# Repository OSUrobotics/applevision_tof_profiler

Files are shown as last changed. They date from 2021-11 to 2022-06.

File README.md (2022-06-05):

# Applevision ToF Profiler

This repository contains all of the code/models required to create the distance sensor characterization setup used by the Apple Vision capstone project. More information on this setup and it's findings can be found in the handoff document TODO.

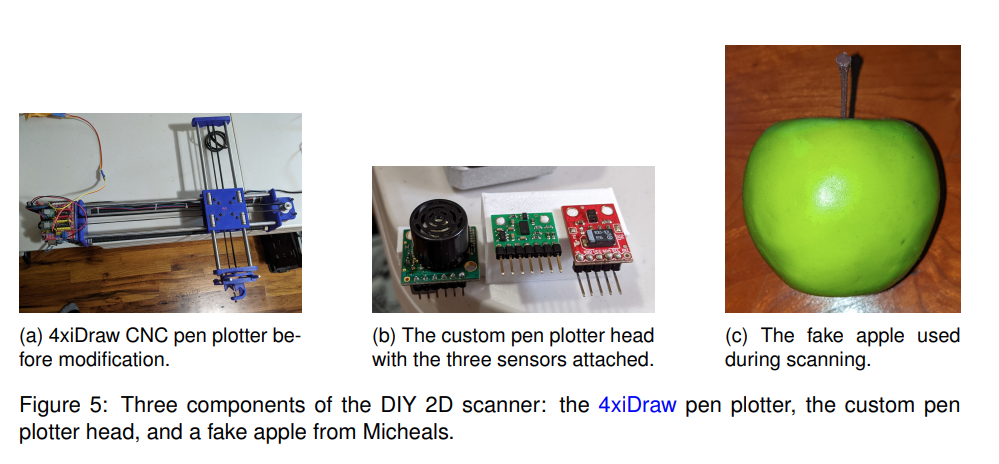
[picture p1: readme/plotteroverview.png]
Diagram from the handoff document showing the pen plotter, sensor testing rig, and fake apple that was scanned


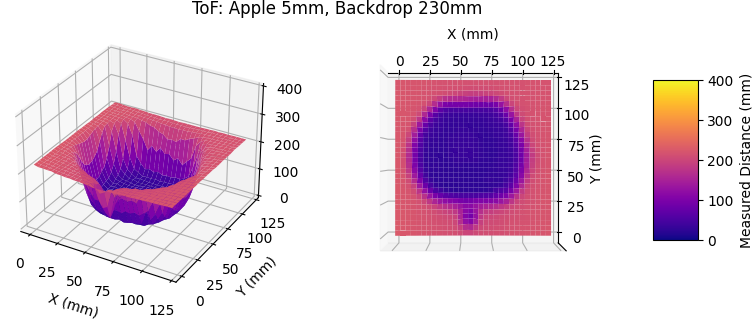
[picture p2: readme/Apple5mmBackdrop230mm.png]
Sample apple scan taken using the VL53L0X ToF sensor


## Repository Structure

```mermaid
flowchart LR
    ultra[MB1232 Ultrasonic Sensor]
    tof[VL53L0X ToF Sensor]
    apd[APDS9960 Proximity Sensor]
    feather[Feather M0]
    plot["4xiDraw Pen Plotter (grbl v1.1h)"]
    comp[Plotter Script]
    data[(CSV Data)]

    ultra --> feather
    tof --> feather
    apd --> feather
    feather <--> comp
    comp <--> plot
    comp --> data
```

This repository splits components of the testing rig into subfolders:
* [`data/`](data/) - Raw CSV data of the apple scans. See the [format document](./data/format.md) for more information.
* [`models/`](models/) - CAD model of the custom pen plotter head in various formats. Originally designed in Autodesk Fusion 360.
* [`plotter_firmware/`](plotter_firmware/) - PlatformIO firmware for a [Feather M0](https://www.adafruit.com/product/2772) to relay sensor readings from the plotter head to the computer.
* [`plotter_script/`](plotter_script/) - Python script which controls the pen plotter and collects data from the sensors.
* [`scripts/`](scripts/) - Scripts to visualize, model, and animate the data collected.

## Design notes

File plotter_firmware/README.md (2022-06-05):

# Plotter Head Firmware

This folder contains a [PlatformIO](https://platformio.org/) project for firmware on a [Feather M0](https://www.adafruit.com/product/2772) which reads three distance sensors and relays the data through a serial port. Sensors are mounted to the custom pen plotter head and wires are connected to the Feather as shown in the wiring diagram below.

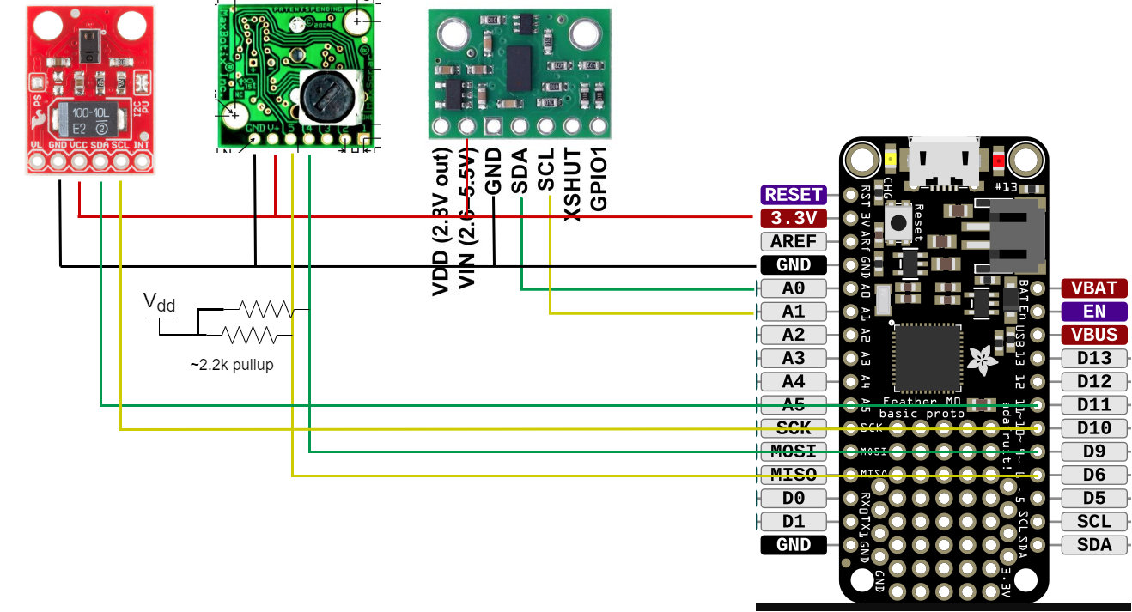
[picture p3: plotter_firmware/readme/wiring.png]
Wiring diagram for the plotter head


Once connected, the Feather M0 will listen on the USB serial port for commands:
* `m`: Take a measurement and print out the result in JSON format.
* `r`: Print `ok` if initialized correctly.

An example of interaction while using this device (input from computer is shown using >):
```console
Init
Ready!
> m
{"lidar": 23, "intensity": 255, "ultra": 20}
> r
ok
```

## I2C

To prevent stupid electrical/driver issues with I2C, each sensor is given it's own I2C bus which it control with impunity. Since the Feather M0 only has one hardware I2C bus, software busses are used on regular GPIO pins. The [`lib`](lib) folder contains sensor drivers that were modified to use a software I2C driver instead of the default `Wire` library (which uses the hardware one).

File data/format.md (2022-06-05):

# Data Format

This folder contains raw readings from the three distance sensors at various XY points. The title of the CSV corresponds to a scanning setup as described in section 2.1.4 of the handoff document TODO. There are four columns present in each CSV:

* `x`, `y` - 2D displacement in millimeters from the top left corner of the scan area.
* `intensity` - Raw value from the APDS9960 proximity sensor ADC. Value is a single byte (0-255). Gain, pulse length, and other sensor settings used during the scan can be found in the [sensor code](../plotter_firmware/src/main.cpp).
* `ultra` - Measured distance in centimeters from the MB1213 ultrasonic sensor.
* `lidar` - Measured distance in millimeters from the VL53L0X ToF sensor. Adafruit's `VL53L0X_SENSE_HIGH_ACCURACY` profile was used for measurement: specific setting values can be found under [`Adafruit_VL53L0X::configSensor`](../plotter_firmware/lib/Adafruit_VL53L0X-master/src/Adafruit_VL53L0X.cpp).

All data files measured a 160mm by 160mm area with a 4mm increment. Five measurements were taken at each grid point to minimize error caused by stopping/starting.

For examples of processing this data, see the scripts in [`visualization_scripts`](../visualization_scripts).

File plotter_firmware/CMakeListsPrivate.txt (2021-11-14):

# !!! WARNING !!! AUTO-GENERATED FILE, PLEASE DO NOT MODIFY IT AND USE
# https://docs.platformio.org/page/projectconf/section_env_build.html#build-flags
#
# If you need to override existing CMake configuration or add extra,
# please create `CMakeListsUser.txt` in the root of project.
# The `CMakeListsUser.txt` will not be overwritten by PlatformIO.

set(CMAKE_CONFIGURATION_TYPES "Debug" CACHE STRING "Build Types reflect PlatformIO Environments" FORCE)

set(CLION_SVD_FILE_PATH "$ENV{HOMEDRIVE}$ENV{HOMEPATH}/.platformio/platforms/atmelsam/misc/svd/ATSAMD21G18A.svd" CACHE FILEPATH "Peripheral Registers Definitions File" FORCE)

SET(CMAKE_C_COMPILER "$ENV{HOMEDRIVE}$ENV{HOMEPATH}/.platformio/packages/toolchain-gccarmnoneeabi/bin/arm-none-eabi-gcc.exe")
SET(CMAKE_CXX_COMPILER "$ENV{HOMEDRIVE}$ENV{HOMEPATH}/.platformio/packages/toolchain-gccarmnoneeabi/bin/arm-none-eabi-g++.exe")
SET(CMAKE_CXX_FLAGS "-fno-rtti -fno-exceptions -std=gnu++11 -fno-threadsafe-statics -Os -ggdb3 -g3 -fasynchronous-unwind-tables -Os -ffunction-sections -fdata-sections -Wall -mcpu=cortex-m0plus -mthumb -nostdlib --param max-inline-insns-single=500 -Wno-expansion-to-defined")
SET(CMAKE_C_FLAGS "-std=gnu11 -Os -ggdb3 -g3 -fasynchronous-unwind-tables -Os -ffunction-sections -fdata-sections -Wall -mcpu=cortex-m0plus -mthumb -nostdlib --param max-inline-insns-single=500 -Wno-expansion-to-defined")

SET(CMAKE_C_STANDARD 11)
set(CMAKE_CXX_STANDARD 11)

if (CMAKE_BUILD_TYPE MATCHES "Debug")
    add_definitions(-DPLATFORMIO=50203)
    add_definitions(-DARDUINO_SAMD_ZERO)
    add_definitions(-DARDUINO_SAMD_FEATHER_M0)
    add_definitions(-DARM_MATH_CM0PLUS)
    add_definitions(-D__SAMD21G18A__)
    add_definitions(-DARDUINO=10805)
    add_definitions(-DF_CPU=48000000L)
    add_definitions(-DUSBCON)
    add_definitions(-DUSB_VID=0x239A)
    add_definitions(-DUSB_PID=0x800B)
    add_definitions(-DUSB_PRODUCT="Adafruit Feather M0")
    add_definitions(-DUSB_MANUFACTURER=\"Adafruit\")
    add_definitions(-DARDUINO_ARCH_SAMD)
    add_definitions(-DUSB_CONFIG_POWER=100)
    add_definitions(-DARDUINO_SAMD_ADAFRUIT)

    include_directories("${CMAKE_CURRENT_LIST_DIR}/include")
    include_directories("${CMAKE_CURRENT_LIST_DIR}/src")
    include_directories("${CMAKE_CURRENT_LIST_DIR}/lib/Adafruit_VL53L0X-master/src")
    include_directories("${CMAKE_CURRENT_LIST_DIR}/.pio/libdeps/Debug/SlowSoftWire")
    include_directories("${CMAKE_CURRENT_LIST_DIR}/.pio/libdeps/Debug/SlowSoftI2CMaster")
    include_directories("${CMAKE_CURRENT_LIST_DIR}/.pio/libdeps/Debug/FeatherTrace/src")
    include_directories("${CMAKE_CURRENT_LIST_DIR}/.pio/libdeps/Debug/Adafruit Arduino Zero ASF Core Library")
    include_directories("$ENV{HOMEDRIVE}$ENV{HOMEPATH}/.platformio/packages/framework-arduino-samd-adafruit/libraries/SPI")
    include_directories("${CMAKE_CURRENT_LIST_DIR}/.pio/libdeps/Debug/Adafruit Zero DMA Library")
    include_directories("${CMAKE_CURRENT_LIST_DIR}/.pio/libdeps/Debug/Adafruit Zero DMA Library/utility")
    include_directories("$ENV{HOMEDRIVE}$ENV{HOMEPATH}/.platformio/packages/framework-arduino-samd-adafruit/libraries/Wire")
    include_directories("$ENV{HOMEDRIVE}$ENV{HOMEPATH}/.platformio/packages/framework-cmsis/CMSIS/Core/Include")
    include_directories("$ENV{HOMEDRIVE}$ENV{HOMEPATH}/.platformio/packages/framework-cmsis-atmel/CMSIS/Device/ATMEL")
    include_directories("$ENV{HOMEDRIVE}$ENV{HOMEPATH}/.platformio/packages/framework-arduino-samd-adafruit/cores/arduino")
    include_directories("$ENV{HOMEDRIVE}$ENV{HOMEPATH}/.platformio/packages/framework-arduino-samd-adafruit/libraries/Adafruit_TinyUSB_Arduino/src/arduino")
    include_directories("$ENV{HOMEDRIVE}$ENV{HOMEPATH}/.platformio/packages/framework-cmsis/CMSIS/DSP/Include")
    include_directories("$ENV{HOMEDRIVE}$ENV{HOMEPATH}/.platformio/packages/framework-arduino-samd-adafruit/variants/feather_m0")
    include_directories("$ENV{HOMEDRIVE}$ENV{HOMEPATH}/.platformio/packages/framework-arduino-samd-adafruit/libraries/Adafruit_TinyUSB_Arduino/src")
    include_directories("${CMAKE_CURRENT_LIST_DIR}/lib/Adafruit_APDS9960-master")
    include_directories("${CMAKE_CURRENT_LIST_DIR}/lib/Adafruit_BusIO-master")
    include_directories("$ENV{HOMEDRIVE}$ENV{HOMEPATH}/.platformio/packages/framework-arduino-samd-adafruit/libraries/Adafruit_ZeroDMA")
    include_directories("$ENV{HOMEDRIVE}$ENV{HOMEPATH}/.platformio/packages/framework-arduino-samd-adafruit/libraries/Adafruit_ZeroDMA/utility")
    include_directories("$ENV{HOMEDRIVE}$ENV{HOMEPATH}/.platformio/packages/framework-arduino-samd-adafruit/libraries/CI_Tests")
    include_directories("$ENV{HOMEDRIVE}$ENV{HOMEPATH}/.platformio/packages/framework-arduino-samd-adafruit/libraries/HID")
    include_directories("$ENV{HOMEDRIVE}$ENV{HOMEPATH}/.platformio/packages/framework-arduino-samd-adafruit/libraries/I2S/src")
    include_directories("$ENV{HOMEDRIVE}$ENV{HOMEPATH}/.platformio/packages/framework-arduino-samd-adafruit/libraries/SAMD_AnalogCorrection/src")
    include_directories("$ENV{HOMEDRIVE}$ENV{HOMEPATH}/.platformio/packages/framework-arduino-samd-adafruit/libraries/SDU/src")
    include_directories("$ENV{HOMEDRIVE}$ENV{HOMEPATH}/.platformio/packages/framework-arduino-samd-adafruit/libraries/Servo/src")
    include_directories("$ENV{HOMEDRIVE}$ENV{HOMEPATH}/.platformio/packages/framework-arduino-samd-adafruit/libraries/USBHost/src")
    include_directories("$ENV{HOMEDRIVE}$ENV{HOMEPATH}/.platformio/packages/toolchain-gccarmnoneeabi/arm-none-eabi/include/c++/9.3.1")
    include_directories("$ENV{HOMEDRIVE}$ENV{HOMEPATH}/.platformio/packages/toolchain-gccarmnoneeabi/arm-none-eabi/include/c++/9.3.1/arm-none-eabi")
    include_directories("$ENV{HOMEDRIVE}$ENV{HOMEPATH}/.platformio/packages/toolchain-gccarmnoneeabi/lib/gcc/arm-none-eabi/9.3.1/include")
    include_directories("$ENV{HOMEDRIVE}$ENV{HOMEPATH}/.platformio/packages/toolchain-gccarmnoneeabi/lib/gcc/arm-none-eabi/9.3.1/include-fixed")
    include_directories("$ENV{HOMEDRIVE}$ENV{HOMEPATH}/.platformio/packages/toolchain-gccarmnoneeabi/arm-none-eabi/include")

    FILE(GLOB_RECURSE EXTRA_LIB_SOURCES
        ${CMAKE_CURRENT_LIST_DIR}/.pio/libdeps/Debug/*.*
    )
endif()

FILE(GLOB_RECURSE SRC_LIST
    ${CMAKE_CURRENT_LIST_DIR}/src/*.*
    ${CMAKE_CURRENT_LIST_DIR}/lib/*.*
    ${CMAKE_CURRENT_LIST_DIR}/test/*.*
)

list(APPEND SRC_LIST ${EXTRA_LIB_SOURCES})

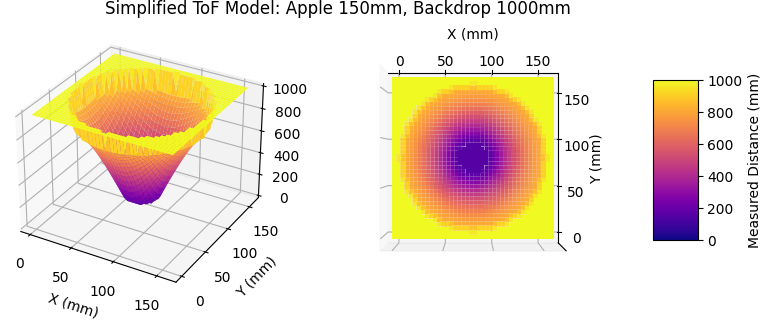
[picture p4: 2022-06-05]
readme/model.png

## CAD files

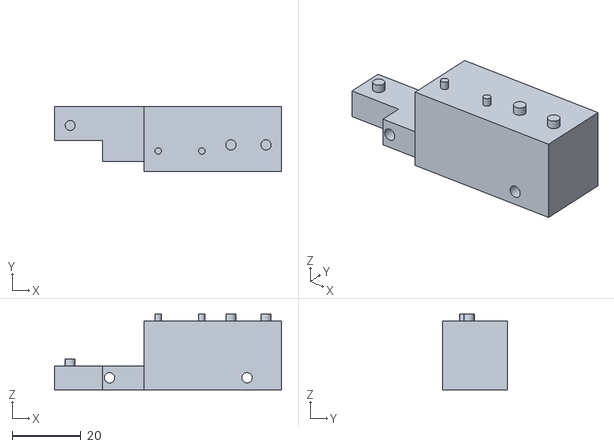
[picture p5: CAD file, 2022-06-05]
models/PenPlotterHead.stl
66.0 x 19.0 x 22.0

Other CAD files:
models/PenPlotterHead.f3z
models/PenPlotterHead.obj

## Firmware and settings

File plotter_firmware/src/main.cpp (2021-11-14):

#include <stdnoreturn.h>
#include <Arduino.h>
#include <Adafruit_APDS9960_SoftWire.h>
#include "wiring_private.h"
#include "FeatherTrace.h"
#include "Adafruit_VL53L0X.h"
#include "SlowSoftI2CMaster.h"
#include "SlowSoftWire.h"

constexpr uint8_t MATBOTIX_WRITE_ADDR = 224;
constexpr uint8_t MATBOTIX_TAKE_READING = 81;
constexpr uint8_t MATBOTIX_READ_ADDR = 225;

FEATHERTRACE_BIND_ALL()

SlowSoftWire lidar_i2c(A0, A1, false);
Adafruit_VL53L0X lidar;
SlowSoftWire apds_i2c(11, 10, false);
Adafruit_APDS9960 intensity;
SlowSoftI2CMaster ultra_i2c(9, 6, true);

void fail(const char* const msg) {
    Serial.println(msg);
    FeatherTrace::Fault(FeatherTrace::FAULT_USER);
}

void setup() {
    // put your setup code here, to run once:
    Serial.begin(115200);
    while(!Serial);
    if (FeatherTrace::DidFault())
      FeatherTrace::PrintFault(Serial);
    Serial.flush();
    // set the watchdog timer to 8 seconds
    FeatherTrace::StartWDT(FeatherTrace::WDTTimeout::WDT_8S);

    Serial.println("Init");
    if (!lidar.begin(VL53L0X_I2C_ADDR, true, &lidar_i2c, Adafruit_VL53L0X::VL53L0X_SENSE_HIGH_ACCURACY))
        fail("Lidar init");

    if (!intensity.begin(200, APDS9960_AGAIN_1X, 0x39, &apds_i2c))
        fail("Intensity init");
    intensity.setProxGain(APDS9960_PGAIN_4X);
    intensity.setLED(APDS9960_LEDDRIVE_100MA, APDS9960_LEDBOOST_100PCNT);
    intensity.setProxPulse(APDS9960_PPULSELEN_16US, 8);
    intensity.enableProximity(true);

    if (!ultra_i2c.i2c_init())
        fail("ultra i2c init");
    if (!ultra_i2c.i2c_start(MATBOTIX_WRITE_ADDR))
        fail("ultra not connected");
    ultra_i2c.i2c_stop();

    MARK;
    Serial.println("Ready!");
    Serial.flush();
}

void take_reading() {
    if (!ultra_i2c.i2c_start(MATBOTIX_WRITE_ADDR))
        fail("ultra not connected");
    ultra_i2c.i2c_write(MATBOTIX_TAKE_READING);
    ultra_i2c.i2c_stop();

    VL53L0X_RangingMeasurementData_t measure;
    lidar.rangingTest(&measure, false);

    bool lidar_valid = false;
    uint16_t lidar_dist = 0;
    if (measure.RangeStatus != 4) {
        lidar_valid = true;
        lidar_dist = measure.RangeMilliMeter;
    }
    else
        lidar_valid = false;

    uint16_t prox_dist = intensity.readProximity();

    if (!ultra_i2c.i2c_start_wait(MATBOTIX_READ_ADDR))
        fail("ultra not connected read");
    uint8_t high = ultra_i2c.i2c_read(false);
    uint8_t low = ultra_i2c.i2c_read(false);
    ultra_i2c.i2c_stop();
    uint16_t ultra_dist = ((uint16_t)high << 8) | (uint16_t)low;

    char buf[1024];
    if (lidar_valid)
        snprintf(buf, sizeof(buf), R"({"lidar": %hu, "intensity": %hu, "ultra": %hu})", lidar_dist, prox_dist, ultra_dist);
    else
        snprintf(buf, sizeof(buf), R"({"intensity": %hu, "ultra": %hu})", prox_dist, ultra_dist);
    Serial.println(buf);
}

void loop() {
    MARK;
    while (!Serial.available())
        MARK;

    const char read = Serial.read();
    switch (read) {
        case 'm':
            take_reading();
            break;
        case 'r':
            Serial.println("ok");
            break;
        default: ;
    }
}

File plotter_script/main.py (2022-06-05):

"""
Pen plotter control script. Adjust the ports then run to automatically
collect a scan of a GRID_MM_SIZE x GRID_MM_SIZE grid in GRID_MM_INC
increments. Outputs the data to a CSV file and plots the lidar live
as it scans.
"""

import time
import json
from typing import Generator, NamedTuple, Optional
from pandas.core.frame import DataFrame

import serial
from mpl_toolkits import mplot3d as Axes3D
import matplotlib.pyplot as plt
from matplotlib import cm
import pandas as pd

from penplotter import Point, PenPlotter

# Serial ports, likley need adjusting per computer
CNC_PORT = 'COM3'
ARDUINO_PORT = 'COM4'
# baud rate to use for serial ports
CNC_BAUD = ARDUINO_BAUD = 115200
# Grid scanning settings
GRID_MM_SIZE = 160
GRID_MM_INC = 4
# Number of times to scan per grid point
SCAN_COUNT_PER = 5


ARDUINO_TAKE_READING = b'm'
ARDUINO_CHECK_OK = b'r'
ARDUINO_FAIL = b'fail'

class SerialDebugProxy(serial.Serial):
    """Repeats serial commuication to stdout for debugging"""
    PREFIX = ''

    def write(self, data: bytes) -> int:
        print(f'->{self.PREFIX}: {data.decode("ascii").strip()}')
        return super().write(data)
    
    def read_until(self, expected: bytes):
        out = super().read_until(expected=expected)
        print(f'<-{self.PREFIX} {out.decode("ascii").strip()}')
        return out

    def readline(self):
        out = super().readline()
        print(f'<-{self.PREFIX} {out.decode("ascii").strip()}')
        return out

class CNCDebugProxy(SerialDebugProxy):
    PREFIX = 'cnc'

class ArduinoDebugProxy(SerialDebugProxy):
    PREFIX = 'arduino'

class SensorReading(NamedTuple):
    ultra: int
    intensity: int
    lidar: Optional[int] = None

class DataPoint(NamedTuple):
    x: float
    y: float
    intensity: int
    ultra: int
    lidar: Optional[int]

    @staticmethod
    def factory(p: Point, r: SensorReading) -> 'DataPoint':
        return DataPoint(p.x, p.y, r.intensity, r.ultra, r.lidar)

def point_grid_zigzag(gridsize: int, gridinc: int) -> Generator[Point, None, None]:
    """Yield points in a gridsize by gridsize grid traversing in a zigzag"""
    for i, x in enumerate(range(0, gridsize + gridinc, gridinc)):
        itery = range(0, gridsize + gridinc, gridinc)
        if i % 2 != 0:
            itery = reversed(itery)
        for y in itery:
            yield Point(x, y)

def take_reading(ser: serial.Serial) -> SensorReading:
    ser.write(ARDUINO_TAKE_READING)
    reading = ser.readline()
    if ARDUINO_FAIL in reading:
        raise RuntimeError(f'Got unexpected output: {reading.decode("ascii")}')
    decoded = json.loads(reading)
    return SensorReading(**decoded)

def wait_or_fail(ser: serial.Serial, check: bytes):
    line = ser.read_until(check)
    if check not in line:
        raise TimeoutError(f'Error when waiting for string "{check}"')

if __name__ == '__main__':
    with CNCDebugProxy(CNC_PORT, CNC_BAUD, timeout=100) as cncser, \
        ArduinoDebugProxy(ARDUINO_PORT, ARDUINO_BAUD, timeout=2) as arduinoser:
        
        plotter = PenPlotter(cncser)
        plotter.reset()
        
        try:
            wait_or_fail(arduinoser, b'Ready!\r\n')
        except TimeoutError:
            arduinoser.write(ARDUINO_CHECK_OK)
            wait_or_fail(arduinoser, b'ok\r\n')

        arduinoser.flushInput()

        print('Devices setup successfully')

        fig = plt.figure()
        ax = fig.add_subplot(111, projection='3d')
        ax.set_xlim(0, 100)
        ax.set_ylim(0, 100)
        ax.set_zlim(0, 1024)
        plt.show(block=False)
        plt.draw()

        graph, = ax.plot([0], [0], [0], '.')

        lidar_points = pd.DataFrame(columns=DataPoint._fields)

        plotter.move_and_stop(Point(-1, 0))
        time.sleep(1)

        for point in point_grid_zigzag(GRID_MM_SIZE, GRID_MM_INC):
            plotter.move_and_stop(point)

            points = []
            for _ in range(SCAN_COUNT_PER):
                measure = take_reading(arduinoser)
                points.append(DataPoint.factory(point, measure))
            lidar_points = pd.concat((lidar_points, pd.DataFrame.from_records(points, columns=DataPoint._fields)), ignore_index=True)

            lidar_points.to_csv('out.csv', index=False)
            z = lidar_points['lidar'].fillna(0).array
            graph.set_data_3d(lidar_points['x'].array, lidar_points['y'].array, z)
            fig.canvas.draw()
            plt.pause(0.01)
        

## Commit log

2021-11-14 feat: first working prototype
2021-11-17 feat: add visualization and two scans
    [apple30mm.csv, apple5mm.csv]
2021-11-17 fix: add multiple figures
    [visualize.py]
2021-12-01 feat: new data and minor changes
    [out150mmnoback.csv, out150mmplantback.csv, out190mm.csv]
2021-12-01 feat: add draft of sensor model
2022-05-20 feat: finalize changes (minus docs)
    [Apple 150mm No Backdrop.csv, Apple 150mm Plant Backdrop.csv, Apple 190mm, Backdrop 400mm.csv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]
2022-06-05 feat: major update for clarity
    [PenPlotterHead.f3z, PenPlotterHead.obj, PenPlotterHead.stl]
